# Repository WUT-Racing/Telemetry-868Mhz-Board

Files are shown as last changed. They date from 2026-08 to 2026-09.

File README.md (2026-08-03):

# System Dwukanałowego Sniffera CAN - Płytka (Hardware)

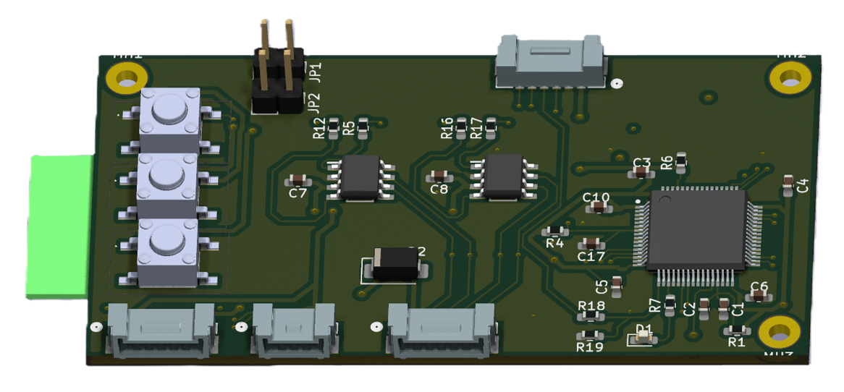
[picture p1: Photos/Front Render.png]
Render 3D zmontowanej płytki


## Opis projektu

Repozytorium zawiera projekt sprzętowy (hardware / PCB) dwukanałowego sniffera CAN, zaprojektowanego na potrzeby telemetrii bolidu Formuły Student.
Głównym zadaniem układu jest bezinwazyjny nasłuch (tryb _silent / bus monitoring_) dwóch niezależnych magistral CAN w pojeździe i przekazywanie zagregowanych ramek przez szybki interfejs UART do zewnętrznego modułu komunikacyjnego (np. modułu radiowego).

Układ został oparty o wydajny mikrokontroler **STM32G484RET6**. Na płytce przewidziano również dedykowany interfejs komunikacyjny dla modułu ESP32, który docelowo ma pełnić rolę nadrzędnego kontrolera filtrującego i konfigurującego.

> **Uwaga:** To repozytorium zawiera wyłącznie projekt płytki drukowanej (schematy, pliki Gerber, BOM). Oprogramowanie układowe (firmware) odpowiedzialne za formatowanie ramek CAN do 12-bajtowych rekordów binarnych znajduje się w osobnym repozytorium.

## Główne parametry sprzętowe

- **Mikrokontroler:** STM32G484RET6 (ARM Cortex-M4, taktowanie 170 MHz)
- **Interfejsy CAN:** 2x kanał sprzętowy dla magistrali Classical CAN (taktowanie do 1 Mbps)
- **Transceivery CAN:** 2x SN65HVD230DR
  - Zasilanie i logika 3.3V
  - Wbudowana terminacja magistrali 120 Ω
- **Interfejs telemetryczny (Radio):** USART2 z obsługą sprzętowej kontroli przepływu RTS/CTS (optymalizowany dla 921600 baud)
- **Interfejs konfiguracyjny (ESP32):** USART1
- **Sygnalizacja stanu:** Dioda LED wyprowadzona na pin PA5
- **Zasilanie układu:** 3.3V

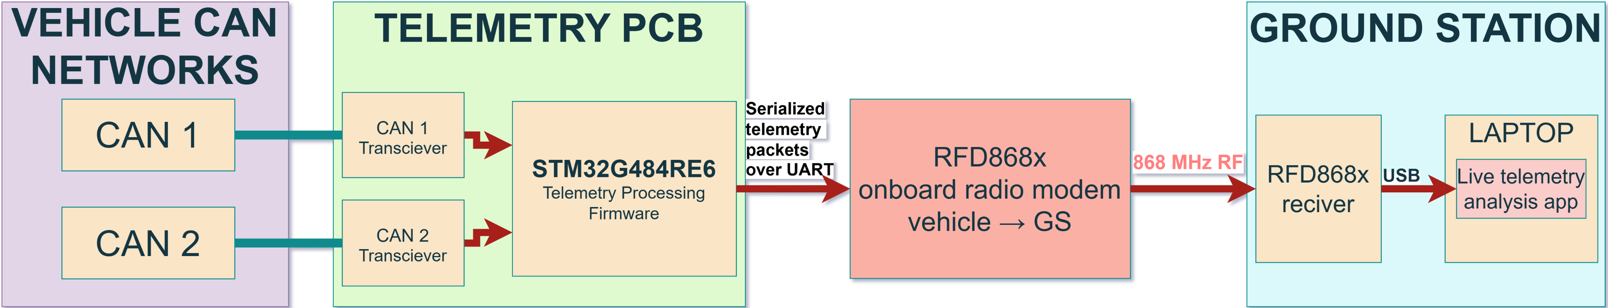
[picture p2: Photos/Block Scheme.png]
Schemat blokowy układu


## Pinout i połączenia zewnętrzne

### Interfejsy CAN (Transceivery)

| Funkcja STM32 | Pin  | Opis połączenia |
| --- | ---- | --- |
| FDCAN1_RX | PA11 | Odbiór ramek z sieci CAN1 |
| FDCAN1_TX | PA12 | Nadawanie CAN1 (w pierwszej wersji programowej sprzęt działa tylko jako odbiornik) |
| FDCAN2_RX | PB12 | Odbiór ramek z sieci CAN2 |
| FDCAN2_TX | PB13 | Nadawanie CAN2 |

### Złącze wyjściowe telemetryczne (Moduł Radiowy)

Współpraca z modułem radiowym realizowana jest przez USART2:
| Funkcja | Pin STM32 | Opis |
|---|---|---|
| USART2_TX | PA2 | Główny strumień danych wysyłany przez DMA do modułu zewn. |
| USART2_RX | PA3 | Odbiór danych z modułu (opcjonalny) |

### Złącze modułu konfigurującego (ESP32)

Połączenie pomiędzy STM32 i ESP32 jest krzyżowe. Wymagane jest też połączenie masy.
| Funkcja STM32 | Pin | Podłączenie po stronie ESP32 |
|---|---|---|
| USART1_TX | PC4 | ESP32 RX |
| USART1_RX | PC5 | ESP32 TX |
| GND | GND | GND |

### Sygnalizacja statusu

| Funkcja | Pin STM32 | Opis sprzętowy |
| --- | --- | --- |
| LED_STATUS | PA5 | Dioda LED; stan wysoki na pinie załącza diodę (szeregowy rezystor 330Ω do GND). |

---

## Galeria PCB

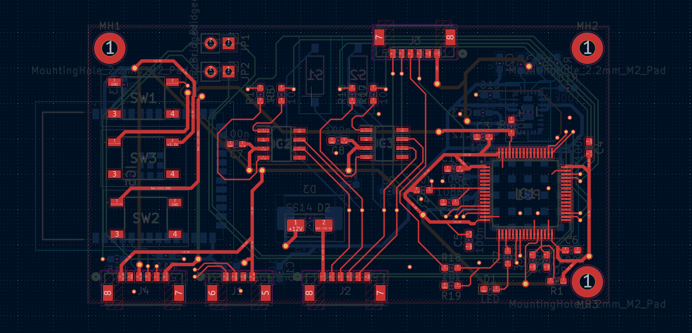
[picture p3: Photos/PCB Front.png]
Zdjęcie PCB Top

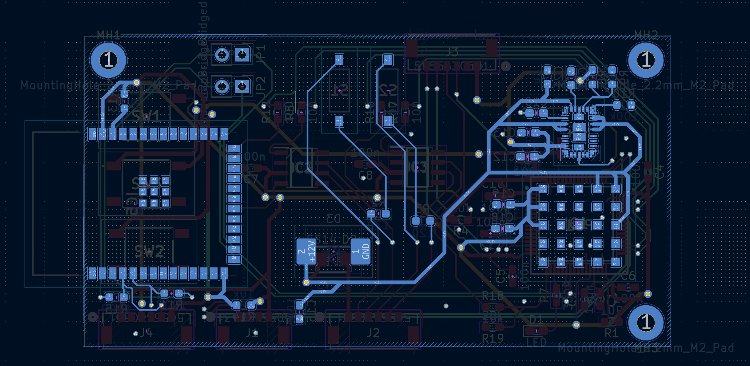
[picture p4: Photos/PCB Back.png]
Zdjęcie PCB Bottom


## Uwagi montażowe i uruchomieniowe

1. **Terminacja CAN:** Płytka posiada zintegrowane rezystory terminujące 120Ω dla obydwu magistral CAN. Upewnij się co do topologii sieci w bolidzie, aby uniknąć zdublowanej terminacji w jednym węźle.
2. **Kontrola przepływu:** Złącze USART2 wspiera linie RTS/CTS. Jeśli podłączany zewnętrzny moduł radiowy nie posiada tych linii sprzętowych, zewrzyj lub skonfiguruj odpowiednio wejścia, aby nie blokować transmisji (zgodnie z ustawieniami peryferiów).
3. **Złącze SWD:** Na płytce wyprowadzono standardowe złącze SWD do programowania i debugowania mikrokontrolera STM32.

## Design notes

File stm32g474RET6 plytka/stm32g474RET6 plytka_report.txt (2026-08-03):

Raport statystyczny PCB
=====================
- Data: 20.04.2026 15:47:55
- Projekt: stm32g474RET6 plytka
- Nazwa płytki: stm32g474RET6 plytka

Płytka
-----
- Szerokość: 73,5000 mm
- Wysokość: 39,0000 mm
- Obszar: 2866,50 mm²
- Górna warstwa miedzi: 401,777 mm²
- Dolna warstwa miedzi: 308,949 mm²
- Min track clearance: 0,2000 mm
- Min track width: 0,2000 mm
- Minimalna średnica otworu: 0,3000 mm
- Grubość stosu warstw płytki: 1,6000 mm

- Front footprint area: 664,474 mm²
- Back footprint area: 994,743 mm²
- Front component density: 23,18 %
- Zagęszczenie elementów po stronie dolnej: 34,70 %
Pola lutownicze
----
- Do montażu przewlekanego: 4
- SMD: 314
- Złącze: 0
- NPTH: 0
- Kastelacja: 0
- Na wcisk: 0

Przelotki
----
- Przelotek na wylot: 57
- Blind vias: 0
- Przelotek zagrzebanych: 0
- Mikroprzelotek: 0

Komponenty
----------

| | Strona górna | Strona dolna | W sumie |
|---|---|---|---|
|THT: | 2 | 0 | 2 |
|SMD: | 34 | 19 | 53 |
|Nieokreślony:  | 0 | 0 | 0 |
|W sumie: | 36 | 19 | 55 |

Otwory wiercone
-----------

| Liczba | Kształt | Rozmiar X | Rozmiar Y | Pokryte | Przelotka/Pole lut | Początkowa warstwa | Warstwa blokująca |
|---|---|---|---|---|---|---|---|
| 39 | Zaokrąglony | 0,3000 mm | 0,3000 mm | PTH | Przelotka | F.Cu | B.Cu |
| 18 | Zaokrąglony | 0,5000 mm | 0,5000 mm | PTH | Przelotka | F.Cu | B.Cu |
| 4 | Zaokrąglony | 1,0000 mm | 1,0000 mm | PTH | Pole lutownicze | F.Cu | B.Cu |

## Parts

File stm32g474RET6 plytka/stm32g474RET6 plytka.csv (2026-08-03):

Reference | Qty | Value | DNP | Exclude from BOM | Exclude from Board | Footprint | Datasheet
C1,C3,C4,C5,C6,C7,C8,C10,C12,C15,C16,C17,C19 | 13 | 100n |  |  |  | Capacitor_SMD:C_0603_1608Metric_Pad1.08x0.95mm_HandSolder
C2,C11,C21 | 3 | 1u |  |  |  | Capacitor_SMD:C_0603_1608Metric_Pad1.08x0.95mm_HandSolder
C13,C14 | 2 | 22u |  |  |  | Capacitor_SMD:C_0603_1608Metric_Pad1.08x0.95mm_HandSolder
C18 | 1 | 10u |  |  |  | Capacitor_SMD:C_0603_1608Metric_Pad1.08x0.95mm_HandSolder
C20 | 1 | 100u |  |  |  | Capacitor_SMD:C_0603_1608Metric_Pad1.08x0.95mm_HandSolder
D1 | 1 | LED |  |  |  | LED_SMD:LED_0603_1608Metric_Pad1.05x0.95mm_HandSolder
D2 | 1 | SS14 |  |  |  | Diode_SMD:D_SMA | https://www.vishay.com/docs/88746/ss12.pdf
D3 | 1 | D_TVS |  |  |  | Diode_SMD:D_SMC
IC1 | 1 | STM32G474RET6 |  |  |  | Telemetry:QFP50P1200X1200X160-64N | https://www.st.com/resource/en/datasheet/stm32g474cb.pdf
IC2,IC3 | 2 | SN65HVD230DR |  |  |  | Telemetry:SOT127P600X175-8N | http://www.ti.com/lit/gpn/sn65hvd230
IC4 | 1 | TPSM63603V3RDHR |  |  |  | Telemetry:TPSM63603EXTRDHR | https://www.ti.com/lit/gpn/TPSM63603
IC5 | 1 | ESP32-S3-WROOM-1-N8 |  |  |  | Telemetry:ESP32S3WROOM1N8R2 | https://www.espressif.com/sites/default/files/documentation/esp32-s3-wroom-1_wroom-1u_datasheet_en.pdf
J1 | 1 | 5055670431 |  |  |  | Telemetry:CONN_505567_04_MOL | https://www.molex.com/en-us/products/part-detail-pdf/5055670431?display=pdf
J2,J3,J4 | 3 | 5055670631 |  |  |  | Telemetry:CONN_505567_06_MOL | https://www.molex.com/en-us/products/part-detail-pdf/5055670631?display=pdf
JP1,JP2 | 2 | Jumper_2_Bridged |  |  |  | Connector_PinHeader_2.54mm:PinHeader_1x02_P2.54mm_Vertical
PS1 | 1 | RPM5.0-3.0-CT |  |  |  | Telemetry:RPM5030CT | https://componentsearchengine.com/Datasheets/1/RPM5.0-3.0-CT.pdf
R1 | 1 | 10R |  |  |  | Resistor_SMD:R_0603_1608Metric_Pad0.98x0.95mm_HandSolder
R2,R3 | 2 | 120 |  |  |  | Resistor_SMD:R_0603_1608Metric_Pad0.98x0.95mm_HandSolder
R4,R6,R13,R14,R18 | 5 | 10k |  |  |  | Resistor_SMD:R_0603_1608Metric_Pad0.98x0.95mm_HandSolder
R5,R12,R16,R17 | 4 | 100 |  |  |  | Resistor_SMD:R_0603_1608Metric_Pad0.98x0.95mm_HandSolder
R7 | 1 | 330R |  |  |  | Resistor_SMD:R_0603_1608Metric_Pad0.98x0.95mm_HandSolder
R8,R10 | 2 | 100k |  |  |  | Resistor_SMD:R_0603_1608Metric_Pad0.98x0.95mm_HandSolder
R9,R19 | 2 | 20k |  |  |  | Resistor_SMD:R_0603_1608Metric_Pad0.98x0.95mm_HandSolder
R11,R15 | 2 | 100R |  |  |  | Resistor_SMD:R_0603_1608Metric_Pad0.98x0.95mm_HandSolder
SW1,SW2,SW3 | 3 | SW_Push |  |  |  | Telemetry:TS406643BK160SMTTR

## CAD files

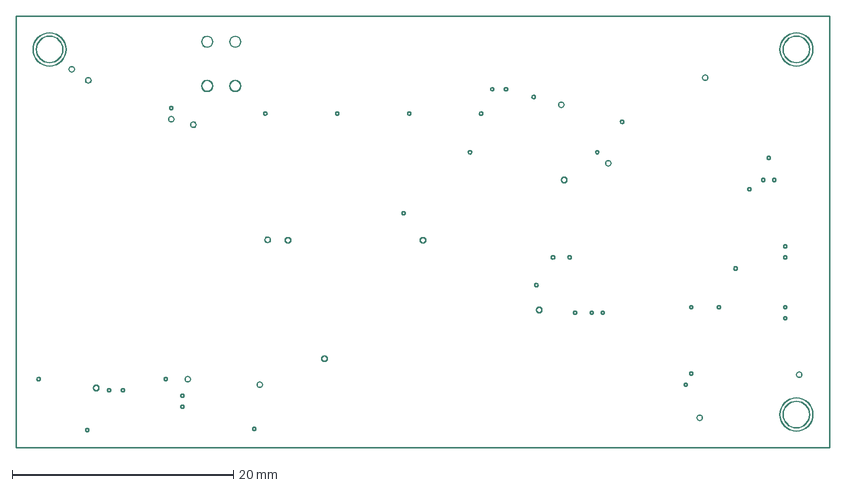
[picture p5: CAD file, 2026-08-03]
stm32g474RET6 plytka/stm32g474RET6 plytka_PCB_1.dxf
73.5 x 39.0 mm

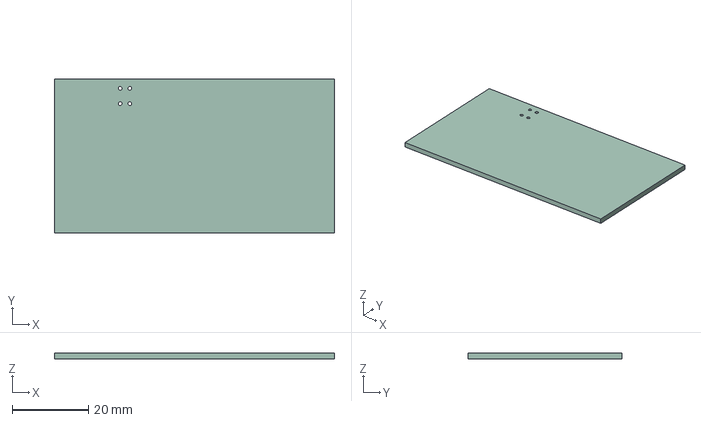
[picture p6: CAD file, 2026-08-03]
stm32g474RET6 plytka/.step
73.5 x 40.5 x 1.51 mm

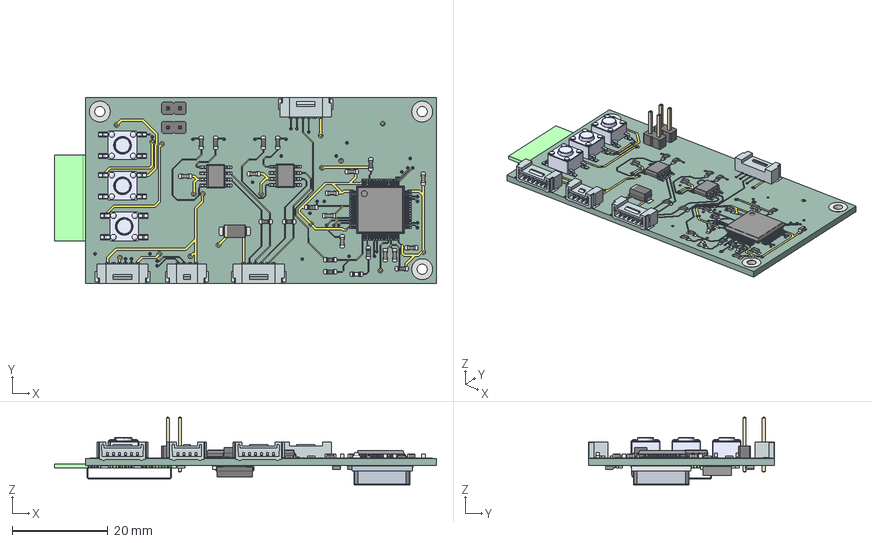
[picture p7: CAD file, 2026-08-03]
stm32g474RET6 plytka/plytkaCAN-UART.step
80.0 x 39.0 x 14.2 mm
R_0603_1608Metric x 19
BODY-SO x 2
LEAD-D0008A x 16
C_0603_1608Metric x 18
LED_0603_1608Metric
PinHeader_1x02_P2.54mm_Vertical x 2
D_SMA
TS04-66-43-BK-160-SMT-TR x 3
PinsArrayLR
PinsArrayTB
ESP32-S3-WROOM-1-N8
Pins
plytkaCAN-UART 1.52.1.1
plytkaCAN-UART 1.52.1.2
RPM_RBB_PCB
RPM_RBB_PCB001
RPM_RBB_PCB002
RPM_RBB_PCB003
RPM_RBB_PCB004
RPM_RBB_PCB005
RPM_RBB_PCB006
RPM_RBB_PCB007
RPM_RBB_PCB008
RPM_RBB_PCB009
RPM_RBB_PCB010
RPM_RBB_PCB011
RPM_RBB_PCB012
RPM_RBB_PCB013
RPM_RBB_PCB014
RPM_RBB_PCB015
RPM_RBB_PCB016
RPM_RBB_PCB017
RPM_RBB_PCB018
RPM_RBB_PCB019
RPM_RBB_PCB020
RPM_RBB_PCB021
RPM_RBB_PCB022
RPM_RBB_PCB023
RPM_RBB_PCB024
RPM_RBB_PCB025
RPM_RBB_PCB026
plytkaCAN-UART 1.52.3.1
D_SMC
stm32g474RET6 plytka_copper
stm32g474RET6 plytka_pad
stm32g474RET6 plytka_via
stm32g474RET6 plytka_PCB

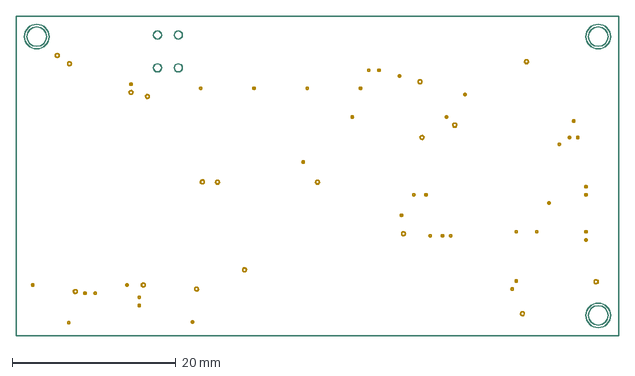
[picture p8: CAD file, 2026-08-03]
stm32g474RET6 plytka/plytkaCAN-UART_step_1.dxf
73.5 x 39.0 mm

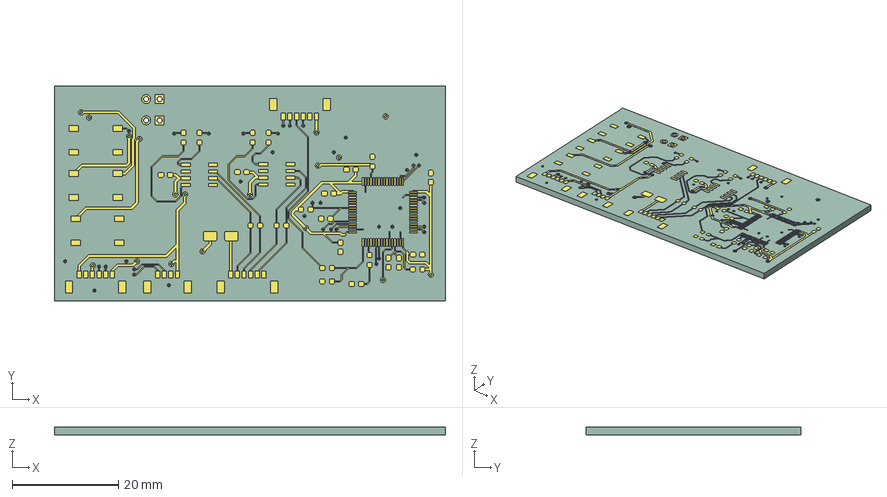
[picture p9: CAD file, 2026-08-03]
stm32g474RET6 plytka/plytka.step
73.5 x 40.5 x 1.59 mm
stm32g474RET6 plytka_copper
stm32g474RET6 plytka_pad
stm32g474RET6 plytka_via
stm32g474RET6 plytka_PCB

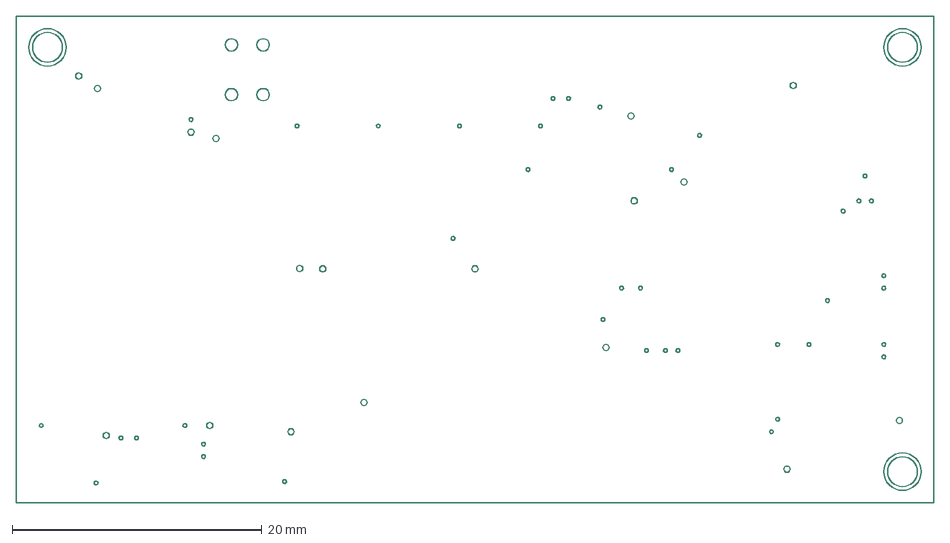
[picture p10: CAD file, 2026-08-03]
stm32g474RET6 plytka/stm32g474RET6 plytka_PCB.dxf
73.5 x 39.0 mm

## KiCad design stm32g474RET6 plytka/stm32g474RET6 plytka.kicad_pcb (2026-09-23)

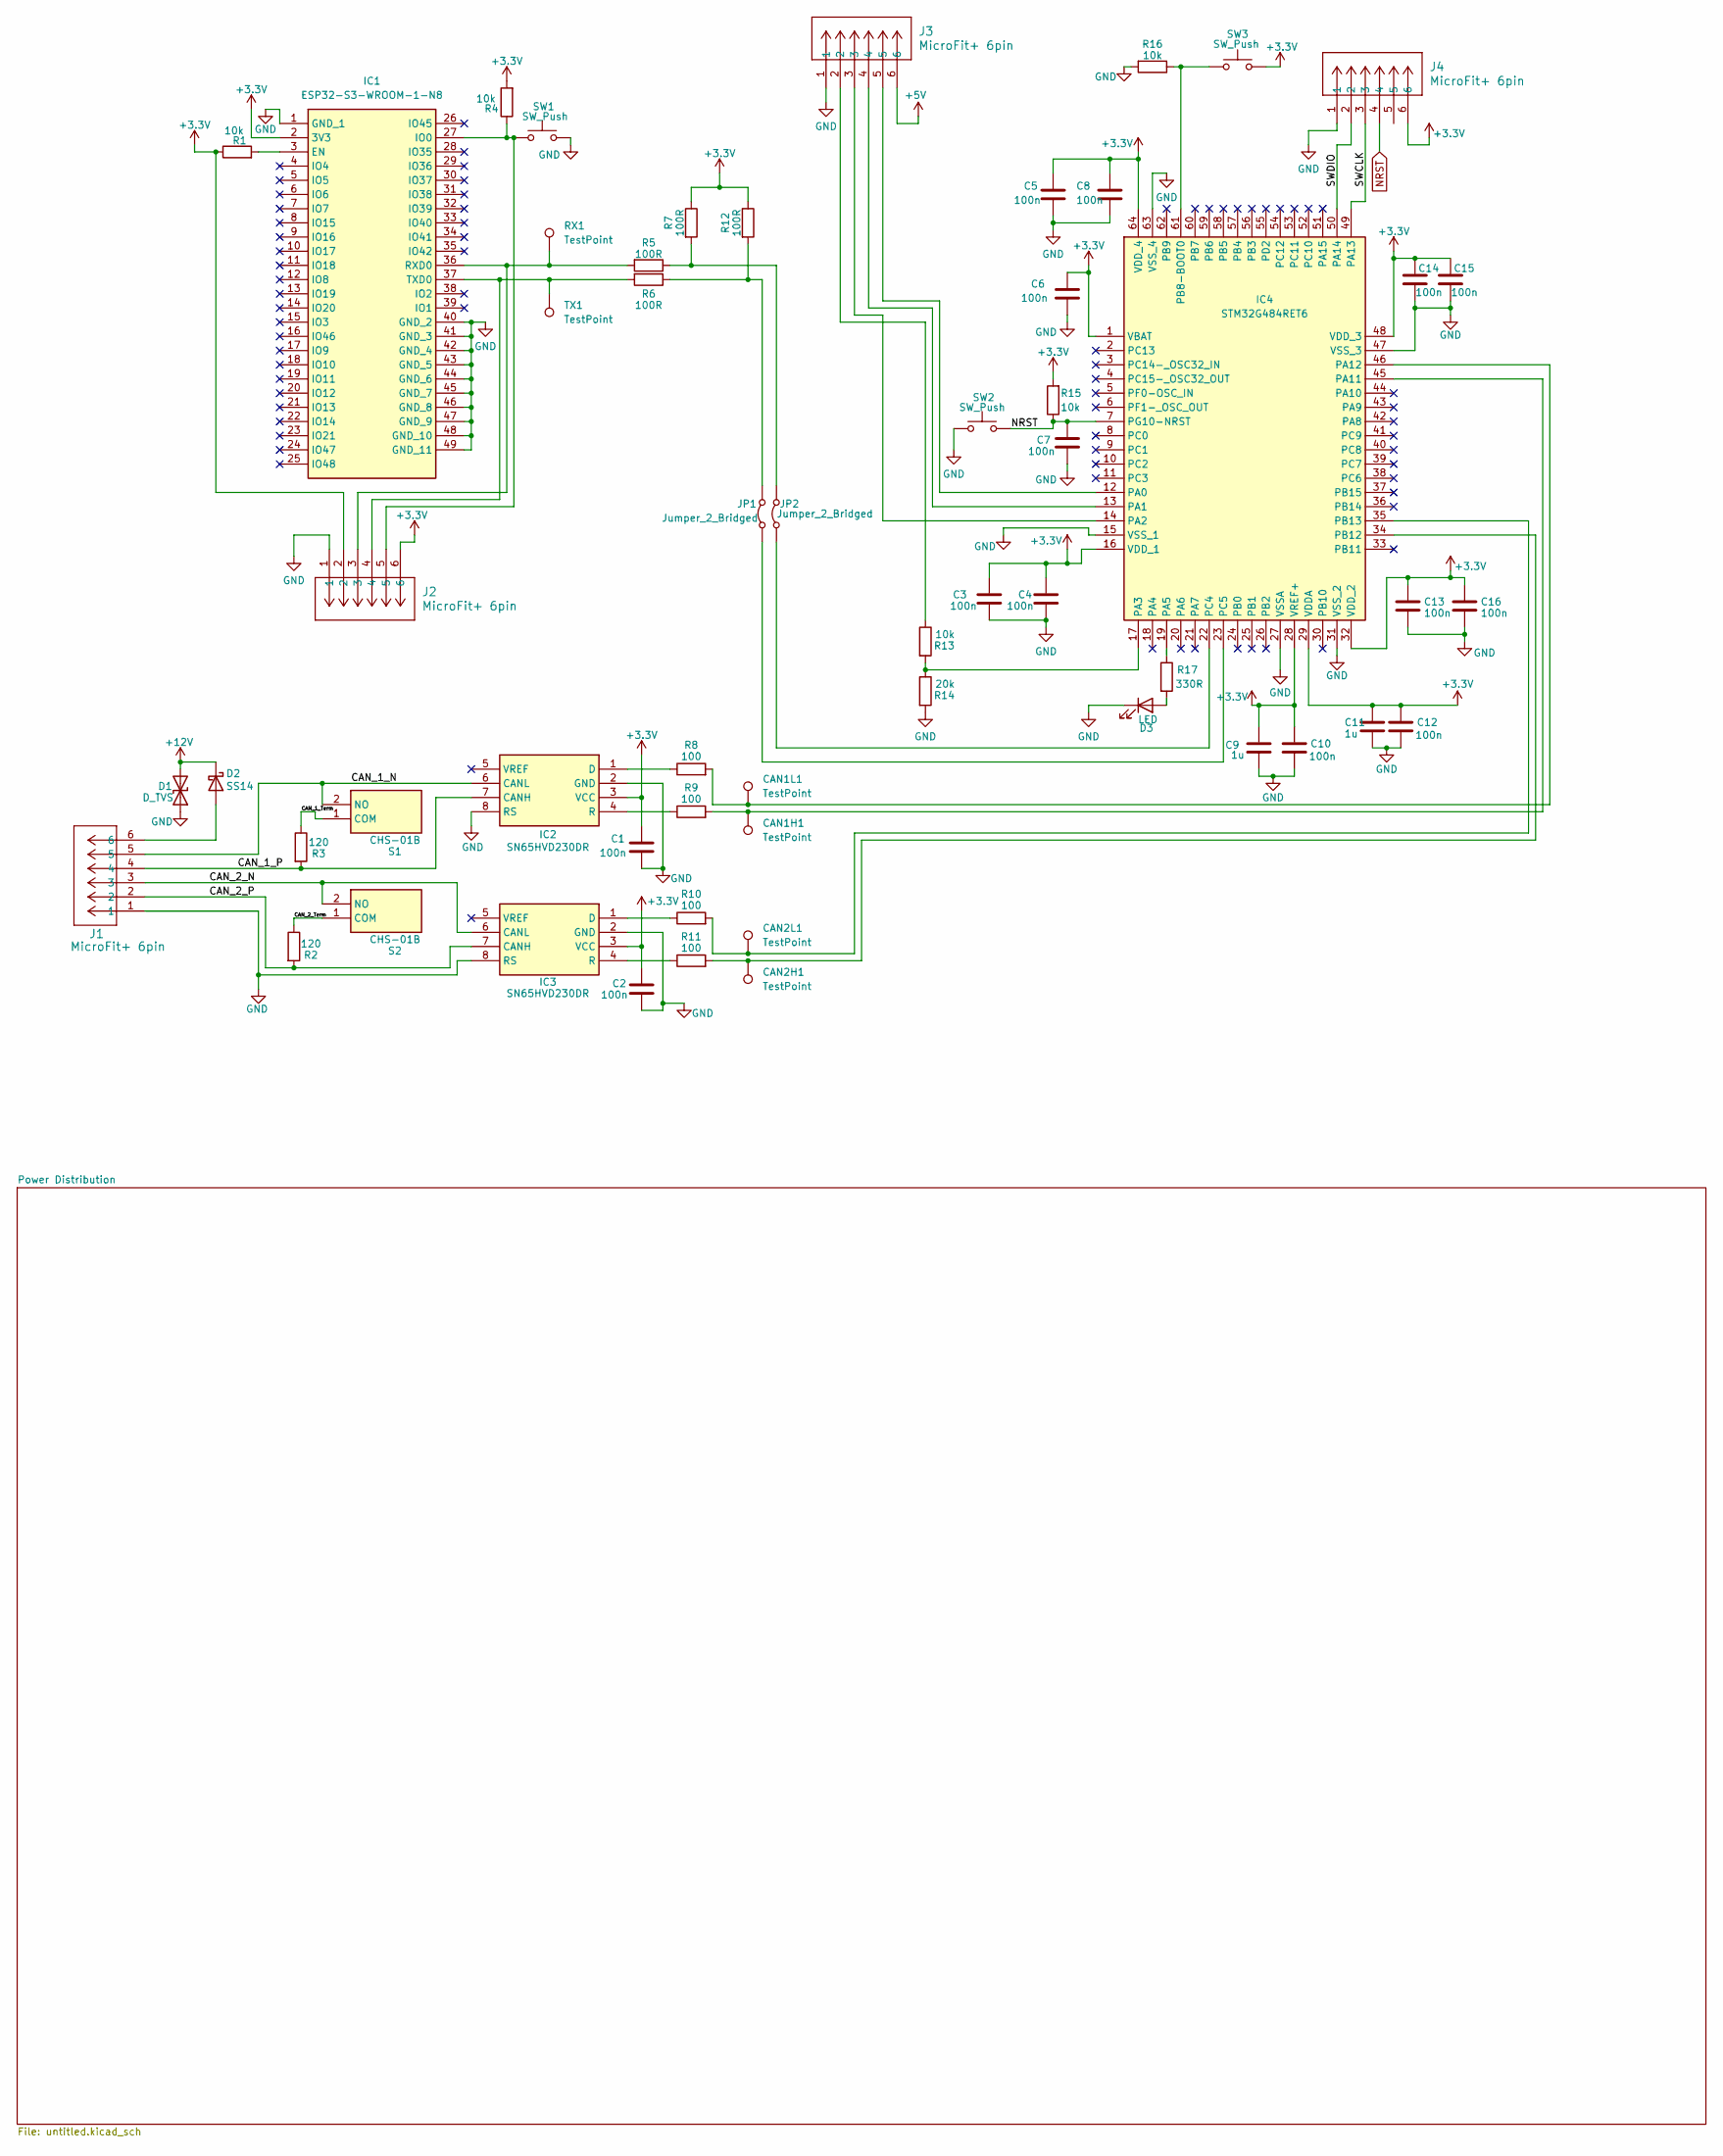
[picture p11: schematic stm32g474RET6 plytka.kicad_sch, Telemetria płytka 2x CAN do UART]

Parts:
C1, C2, C3, C4, C5, C6, C7, C8, C10, C12, C13, C14, C15, C16: 100n; C_0603_1608Metric_Pad1.08x0.95mm_HandSolder
C9, C11: 1u; C_0603_1608Metric_Pad1.08x0.95mm_HandSolder
CAN1H1, CAN1L1, CAN2H1, CAN2L1: TestPoint; TestPoint_THTPad_1.5x1.5mm_Drill0.7mm
D1: D_TVS; D_SMC
D2: SS14; D_SMA
D3: LED; LED_0603_1608Metric_Pad1.05x0.95mm_HandSolder
IC1: ESP32-S3-WROOM-1-N8; ESP32S3WROOM1N8R2; Mouser Part Number 356-ESP32-S3WROOM1N8
IC2, IC3: SN65HVD230DR; SOT127P600X175-8N; Mouser Part Number 595-SN65HVD230DR
IC4: STM32G484RET6; QFP50P1200X1200X160-64N; Mouser Part Number 511-STM32G484RET6
J1, J2, J3, J4: MicroFit+ 6pin; CONN_2125280000_06_MOL
JP1, JP2: Jumper_2_Bridged; PinHeader_1x02_P2.54mm_Vertical
R1, R4, R13, R15, R16: 10k; R_0603_1608Metric_Pad0.98x0.95mm_HandSolder
R2, R3: 120; R_0603_1608Metric_Pad0.98x0.95mm_HandSolder
R5, R6, R7, R12: 100R; R_0603_1608Metric_Pad0.98x0.95mm_HandSolder
R8, R9, R10, R11: 100; R_0603_1608Metric_Pad0.98x0.95mm_HandSolder
R14: 20k; R_0603_1608Metric_Pad0.98x0.95mm_HandSolder
R17: 330R; R_0603_1608Metric_Pad0.98x0.95mm_HandSolder
RX1: TestPoint; TestPoint_THTPad_1.5x1.5mm_Drill0.7mm
S1, S2: CHS-01B; CHS01TB; Mouser Part Number 229-CHS-01B
SW1, SW2, SW3: SW_Push; TS406643BK160SMTTR
TX1: TestPoint; TestPoint_THTPad_1.5x1.5mm_Drill0.7mm

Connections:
+3.3V: C1.1, C2.1, C3.1, C4.1, C5.1, C6.1, C8.1, C9.1, C10.1, C11.1, C12.1, C13.1, C14.1, C15.1, C16.1, IC1.2 (3V3), IC2.3 (VCC), IC3.3 (VCC), IC4.1 (VBAT), IC4.16 (VDD_1), IC4.28 (VREF+), IC4.29 (VDDA), IC4.32 (VDD_2), IC4.48 (VDD_3), IC4.64 (VDD_4), J2.2, J2.6, J4.6, R1.1, R4.2, R7.1, R12.1, R15.2, SW3.2; also elsewhere on the board
+5V: J3.6; also elsewhere on the board
+12V: D1.2 (A2), D2.1 (K); also elsewhere on the board
/CAN_1_N: IC2.6 (CANL), J1.5, S1.2 (NO)
/CAN_1_P: IC2.7 (CANH), J1.4, R3.2
/CAN_1_Term: R3.1, S1.1 (COM)
/CAN_2_N: IC3.6 (CANL), J1.3, S2.2 (NO)
/CAN_2_P: IC3.7 (CANH), J1.2, R2.2
/CAN_2_Term: R2.1, S2.1 (COM)
/SWCLK: IC4.49 (PA13), J4.3
/SWDIO: IC4.50 (PA14), J4.2
GND: C1.2, C2.2, C3.2, C4.2, C5.2, C6.2, C7.2, C8.2, C9.2, C10.2, C11.2, C12.2, C13.2, C14.2, C15.2, C16.2, D1.1 (A1), D3.1 (K), IC1.1 (GND_1), IC1.40 (GND_2), IC1.41 (GND_3), IC1.42 (GND_4), IC1.43 (GND_5), IC1.44 (GND_6), IC1.45 (GND_7), IC1.46 (GND_8), IC1.47 (GND_9), IC1.48 (GND_10), IC1.49 (GND_11), IC2.2 (GND), IC2.8 (RS), IC3.2 (GND), IC3.8 (RS), IC4.15 (VSS_1), IC4.27 (VSSA), IC4.31 (VSS_2), IC4.47 (VSS_3), IC4.63 (VSS_4), J1.1, J2.1, J3.1, J4.1, R14.2, R16.2, SW1.2, SW2.1; also elsewhere on the board
NRST: C7.1, IC4.7 (PG10-NRST), J4.4, R15.1, SW2.2
unnamed: D2.2 (A), J1.6
unnamed: D3.2 (A), R17.2
unnamed: IC1.3 (EN), R1.2
unnamed: IC1.27 (IO0), J2.5, R4.1, SW1.1
unnamed: IC1.36 (RXD0), J2.3, R5.2, RX1.1 (1_1)
unnamed: IC1.37 (TXD0), J2.4, R6.2, TX1.1 (1_1)
unnamed: IC2.1 (D), R8.1
unnamed: IC2.4 (R), R9.1
unnamed: IC3.1 (D), R10.1
unnamed: IC3.4 (R), R11.1
unnamed: IC4.12 (PA0), J3.5
unnamed: IC4.13 (PA1), J3.4
unnamed: IC4.14 (PA2), J3.3
unnamed: IC4.17 (PA3), R13.2, R14.1
unnamed: IC4.19 (PA5), R17.1
unnamed: CAN1H1.1 (1_1), IC4.45 (PA11), R9.2
unnamed: CAN1L1.1 (1_1), IC4.46 (PA12), R8.2
unnamed: IC4.61 (PB8-BOOT0), R16.1, SW3.1
unnamed: CAN2H1.1 (1_1), IC4.34 (PB12), R11.2
unnamed: CAN2L1.1 (1_1), IC4.35 (PB13), R10.2
unnamed: IC4.22 (PC4), JP2.1 (A)
unnamed: IC4.23 (PC5), JP1.1 (A)
unnamed: J3.2, R13.1
unnamed: JP1.2 (B), R6.1, R12.2
unnamed: JP2.2 (B), R5.1, R7.2

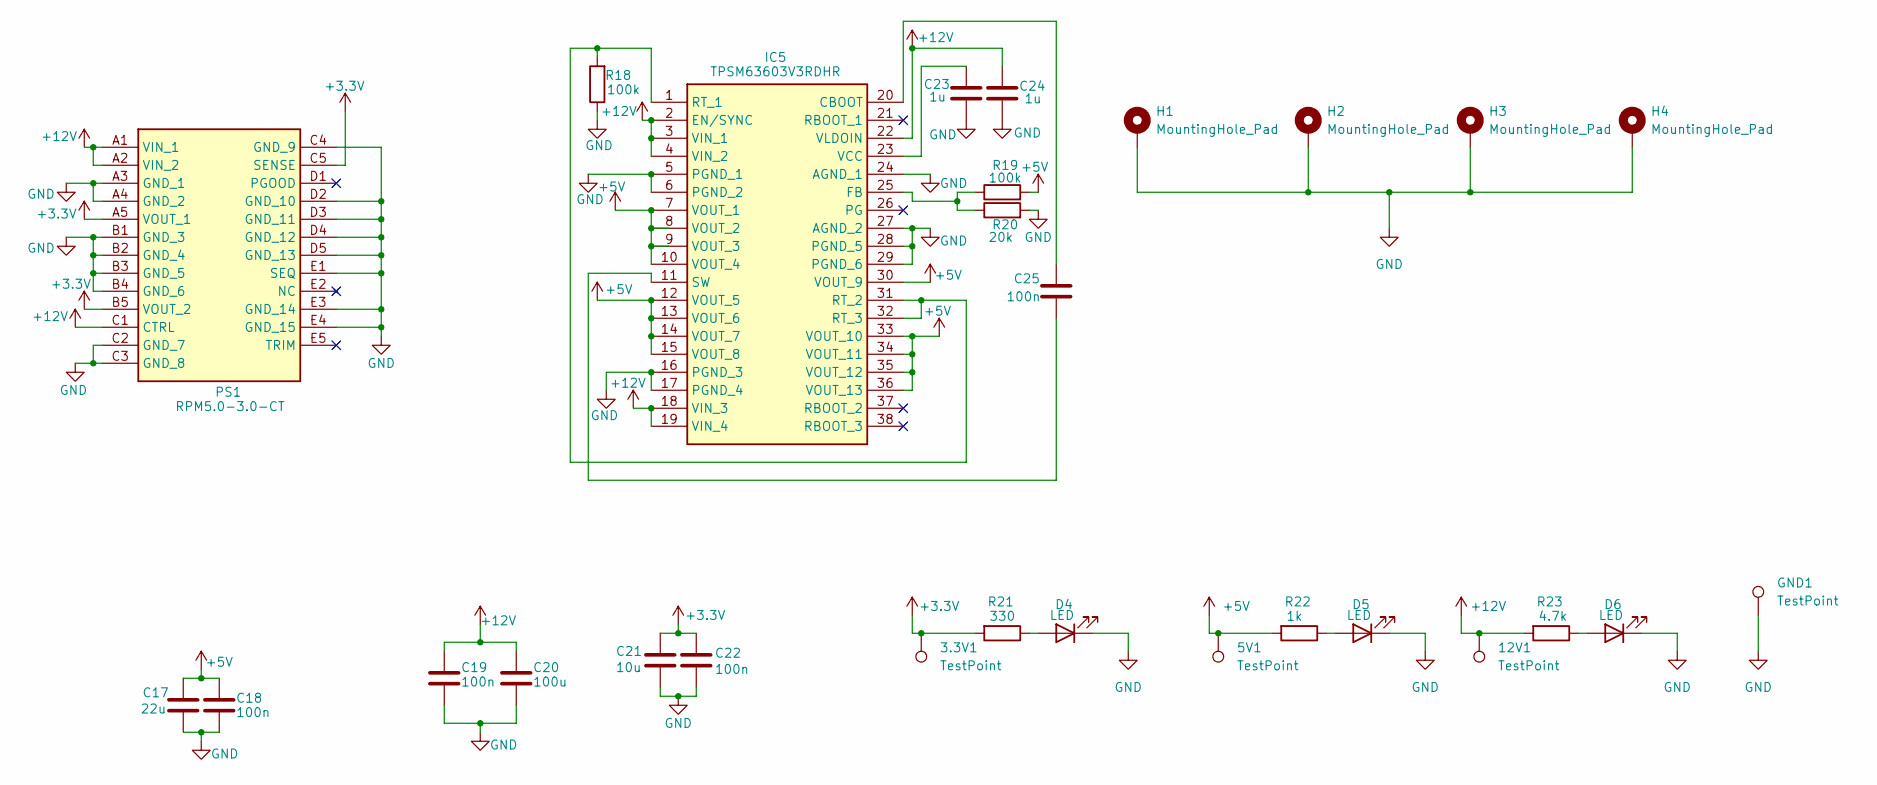
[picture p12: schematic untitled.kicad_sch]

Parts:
3.3V1, 5V1, 12V1: TestPoint; TestPoint_THTPad_1.5x1.5mm_Drill0.7mm
C17: 22u; C_0603_1608Metric_Pad1.08x0.95mm_HandSolder
C18, C19, C22, C25: 100n; C_0603_1608Metric_Pad1.08x0.95mm_HandSolder
C20: 100u; C_0603_1608Metric_Pad1.08x0.95mm_HandSolder
C21: 10u; C_0603_1608Metric_Pad1.08x0.95mm_HandSolder
C23, C24: 1u; C_0603_1608Metric_Pad1.08x0.95mm_HandSolder
D4, D5, D6: LED; LED_0603_1608Metric_Pad1.05x0.95mm_HandSolder
GND1: TestPoint; TestPoint_Loop_D2.50mm_Drill1.0mm
H1, H2, H3, H4: MountingHole_Pad; MountingHole_3.2mm_M3_DIN965_Pad
IC5: TPSM63603V3RDHR; TPSM63603EXTRDHR; Mouser Part Number 595-TPSM63603V3RDHR
PS1: RPM5.0-3.0-CT; RPM5030CT; Mouser Part Number 919-RPM5.0-3.0-CT
R18, R19: 100k; R_0603_1608Metric_Pad0.98x0.95mm_HandSolder
R20: 20k; R_0603_1608Metric_Pad0.98x0.95mm_HandSolder
R21: 330; R_0603_1608Metric_Pad0.98x0.95mm_HandSolder
R22: 1k; R_0603_1608Metric_Pad0.98x0.95mm_HandSolder
R23: 4.7k; R_0603_1608Metric_Pad0.98x0.95mm_HandSolder

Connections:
+3.3V: 3.3V1.1 (1_1), C21.1, C22.1, PS1.A5 (VOUT_1), PS1.B5 (VOUT_2), PS1.C5 (SENSE), R21.2; also elsewhere on the board
+5V: 5V1.1 (1_1), C17.1, C18.1, IC5.7 (VOUT_1), IC5.8 (VOUT_2), IC5.9 (VOUT_3), IC5.10 (VOUT_4), IC5.12 (VOUT_5), IC5.13 (VOUT_6), IC5.14 (VOUT_7), IC5.15 (VOUT_8), IC5.30 (VOUT_9), IC5.33 (VOUT_10), IC5.34 (VOUT_11), IC5.35 (VOUT_12), IC5.36 (VOUT_13), R19.2, R22.2; also elsewhere on the board
+12V: 12V1.1 (1_1), C19.1, C20.1, C24.1, IC5.2 (EN/SYNC), IC5.3 (VIN_1), IC5.4 (VIN_2), IC5.18 (VIN_3), IC5.19 (VIN_4), IC5.22 (VLDOIN), PS1.A1 (VIN_1), PS1.A2 (VIN_2), PS1.C1 (CTRL), R23.2; also elsewhere on the board
GND: C17.2, C18.2, C19.2, C20.2, C21.2, C22.2, C23.2, C24.2, D4.1 (K), D5.1 (K), D6.1 (K), GND1.1 (1_1), H1.1 (1_1), H2.1 (1_1), H3.1 (1_1), H4.1 (1_1), IC5.5 (PGND_1), IC5.6 (PGND_2), IC5.16 (PGND_3), IC5.17 (PGND_4), IC5.24 (AGND_1), IC5.27 (AGND_2), IC5.28 (PGND_5), IC5.29 (PGND_6), PS1.A3 (GND_1), PS1.A4 (GND_2), PS1.B1 (GND_3), PS1.B2 (GND_4), PS1.B3 (GND_5), PS1.B4 (GND_6), PS1.C2 (GND_7), PS1.C3 (GND_8), PS1.C4 (GND_9), PS1.D2 (GND_10), PS1.D3 (GND_11), PS1.D4 (GND_12), PS1.D5 (GND_13), PS1.E1 (SEQ), PS1.E3 (GND_14), PS1.E4 (GND_15), R18.1, R20.2; also elsewhere on the board
unnamed: D4.2 (A), R21.1
unnamed: D5.2 (A), R22.1
unnamed: D6.2 (A), R23.1
unnamed: C25.1, IC5.20 (CBOOT)
unnamed: IC5.25 (FB), R19.1, R20.1
unnamed: IC5.1 (RT_1), IC5.31 (RT_2), IC5.32 (RT_3), R18.2
unnamed: C25.2, IC5.11 (SW)
unnamed: C23.1, IC5.23 (VCC)

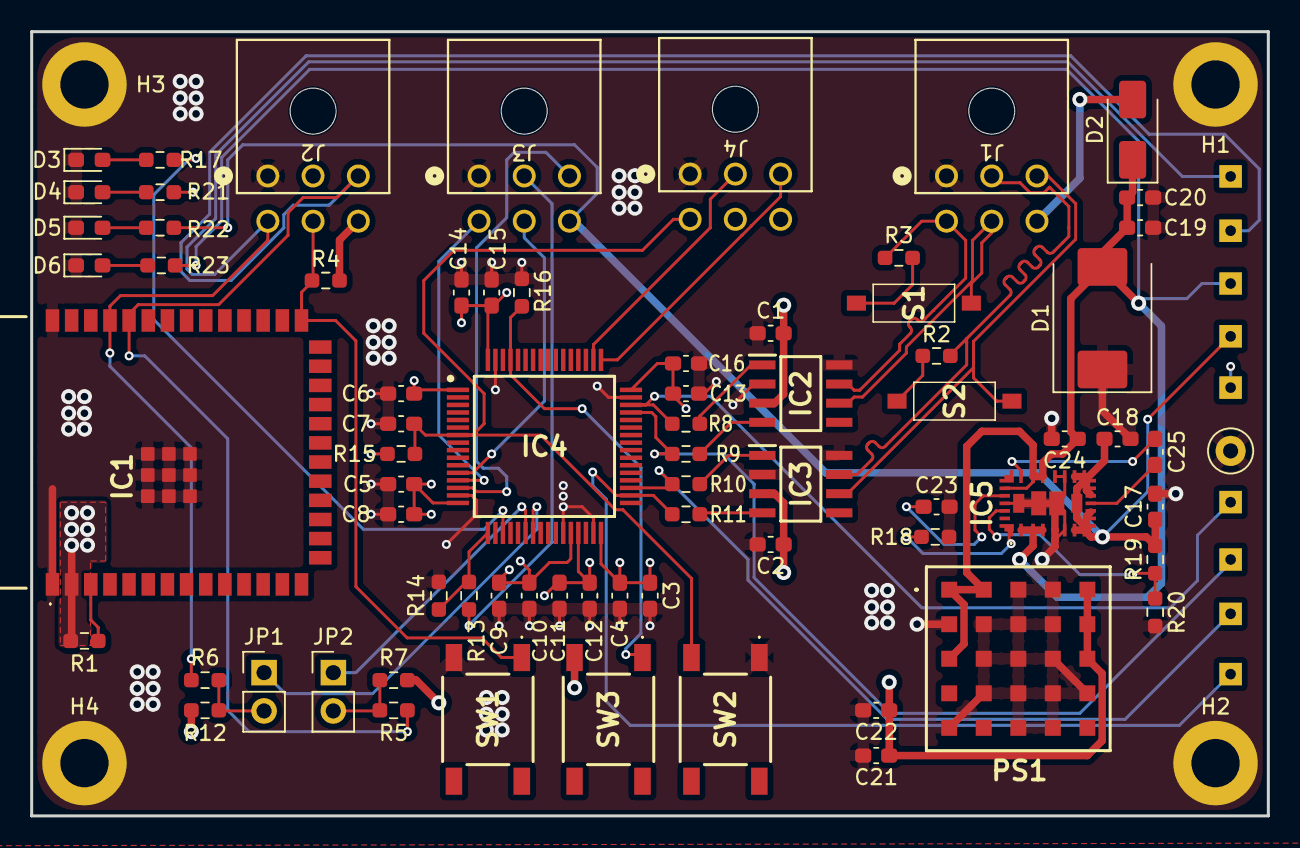
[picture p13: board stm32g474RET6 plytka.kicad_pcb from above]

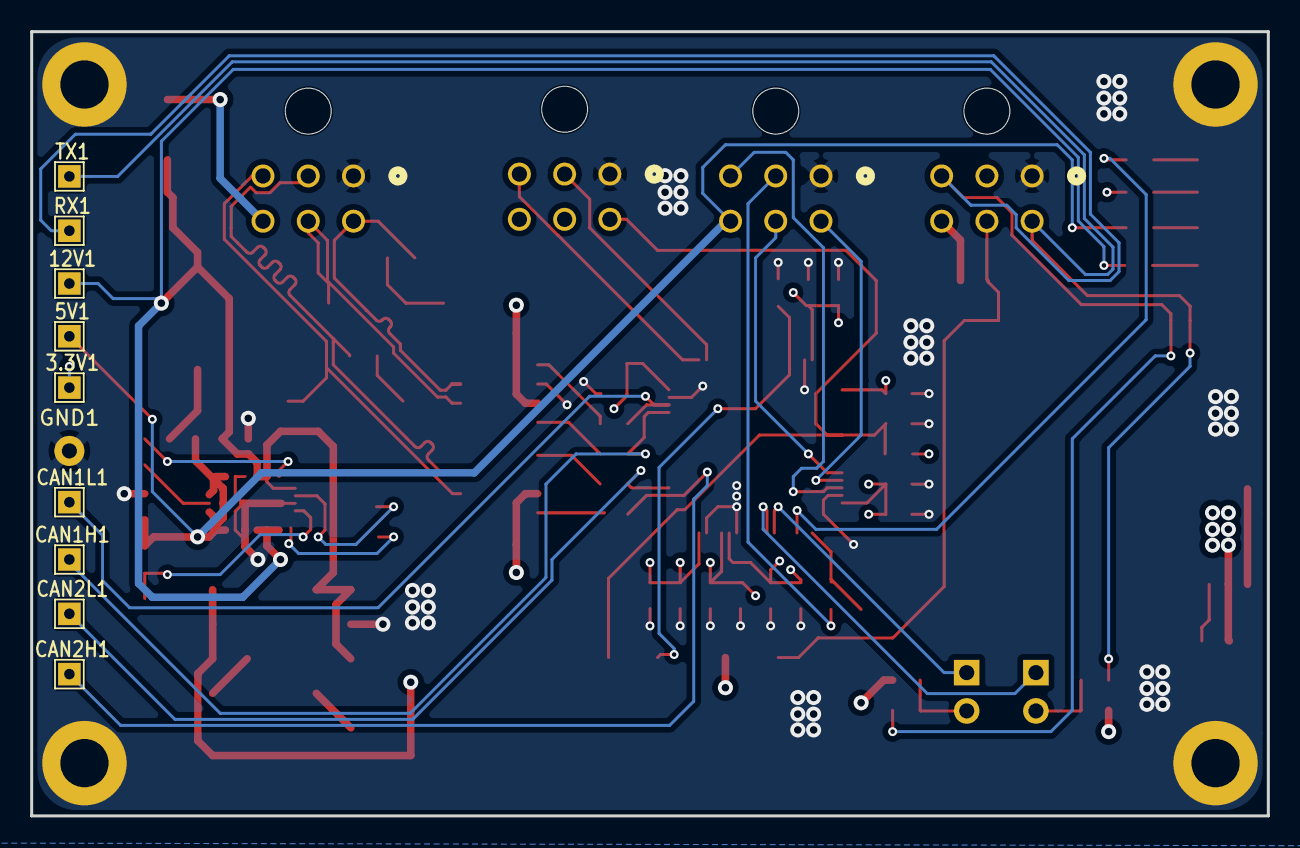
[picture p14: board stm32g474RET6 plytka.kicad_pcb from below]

Board: 4 copper layers, 82.0 x 52.0 mm, 85 parts (9 on the bottom side), 46 nets.

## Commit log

2026-08-03 transfer files to github
    [.step, plytka.step, plytkaCAN-UART.step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]
2026-09-19 added test points
    [stm32g474RET6 plytka.kicad_pcb, stm32g474RET6 plytka.kicad_sch, untitled.kicad_sch]
